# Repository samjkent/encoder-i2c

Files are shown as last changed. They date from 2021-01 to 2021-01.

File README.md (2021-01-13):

# EAW0J 128 Absolute Encoders and LEDs

128 position encoders with LEDs to display state

Encoder input is read using an MCP23017, and LED state is set using an HT16K33

# Large 

128 LEDs in a ring around a single encoder, with a circumference of roughly 6cm

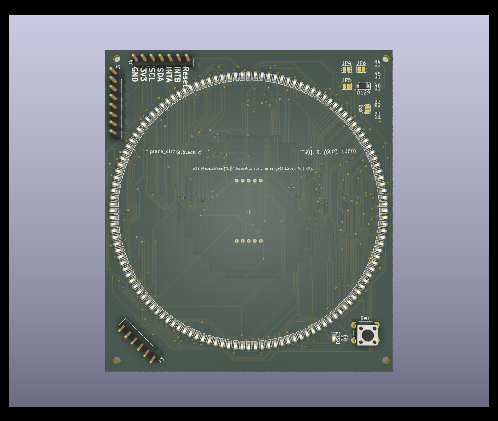
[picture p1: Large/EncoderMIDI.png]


# Small

4 encoders with 32 LEDs per encoder. Requires 2 MCP23017 to provide enough inputs for the encoders.

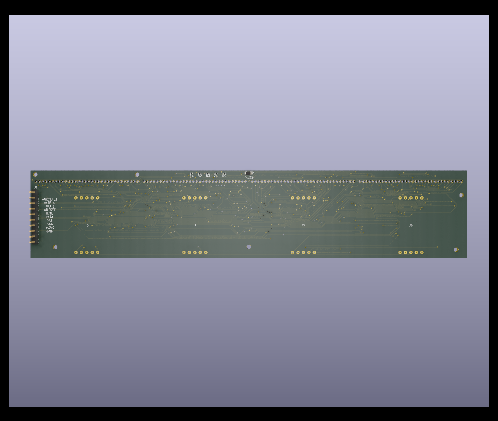
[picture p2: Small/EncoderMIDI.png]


# Example Application

Combined with [samjkent/stm32f4-midi-brain](https://github.com/samjkent/stm32f4-midi-brain) to create a MIDI controller

midi

# Note

The encoder footprint used in these schematics contains a mistake where pins 9 and 10 switched. Software for the current hardware takes this into account.

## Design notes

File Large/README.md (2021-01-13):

# Encoder I2C Large

Kicad layout for a Bourns EAW0J 128 Absolute Encoder with a large ring of LEDs around it

Encoder and LEDs are controlled via I2C (MCP23017, HT16K33)

!(render)[imgurl]

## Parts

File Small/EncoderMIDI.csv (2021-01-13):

Comment | Designator | Footprint | LCSC
LED | D1,D17,D34,D50,D67,D83,D100,D116,D2,D18,D35,D51,D68,D84,D101,D117,D3,D19,D36,D52,D69,D85,D102,D118,D4,D20,D37,D53,D70,D86,D103,D119,D5,D21,D38,D54,D71,D87,D104,D120,D6,D22,D39,D55,D72,D88,D105,D121,D7,D23,D40,D56,D73,D89,D106,D122,D8,D24,D41,D57,D74,D90,D107,D123,D9,D25,D42,D58,D75,D91,D108,D124,D10,D26,D43,D59,D76,D92,D109,D125,D11,D27,D44,D60,D77,D93,D110,D126,D12,D28,D45,D61,D78,D94,D111,D127,D13,D29,D46,D62,D79,D95,D112,D128,D14,D30,D47,D63,D80,D96,D113,D129,D15,D31,D48,D64,D81,D97,D114,D130,D16,D32,D49,D65,D82,D98,D115,D131 | LED_SMD:LED_0603_1608Metric | C2290
D | D132 | Diode_SMD:D_SOD-123F | C162732
Conn_01x10_Female | J1 | Connector_PinHeader_2.54mm:PinHeader_1x10_P2.54mm_Vertical
HT16K33 | J2 | Package_SO:SOIC-28W_7.5x17.9mm_P1.27mm
Conn_01x10_Female | J3,J4,J5,J6 | Rotary_Encoder:EAW0J
SolderJumper_3_Open | JP2,JP5,JP1,JP4,JP6,JP3 | Jumper:SolderJumper-3_P1.3mm_Open_Pad1.0x1.5mm_NumberLabels
SolderJumper_2_Bridged | JP7,JP8 | Jumper:SolderJumper-2_P1.3mm_Bridged2Bar_RoundedPad1.0x1.5mm
SolderJumper_2_Open | JP9,JP10,JP11 | Jumper:SolderJumper-2_P1.3mm_Open_RoundedPad1.0x1.5mm
4.7K | R1,R2 | Resistor_SMD:R_0402_1005Metric | C25940
39K | R3,R4,R5 | Resistor_SMD:R_0402_1005Metric | C159976
MCP23017-E_SO | U1,U2 | Package_SO:SOIC-28W_7.5x17.9mm_P1.27mm

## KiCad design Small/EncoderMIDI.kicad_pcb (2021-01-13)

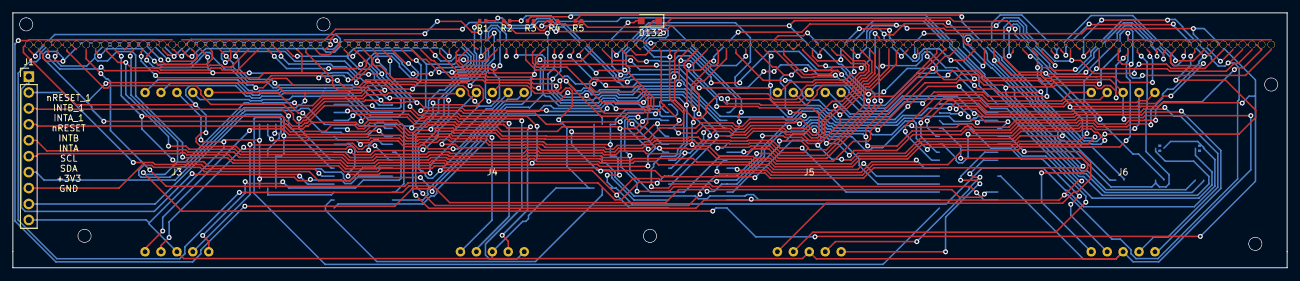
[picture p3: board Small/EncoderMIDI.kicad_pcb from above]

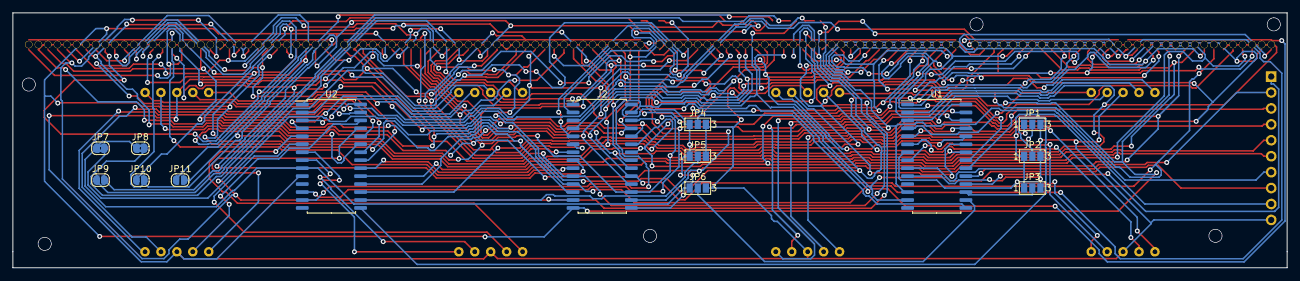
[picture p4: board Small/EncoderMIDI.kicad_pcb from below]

Board: 2 copper layers, 203.2 x 40.6 mm, 153 parts (14 on the bottom side), 58 nets.

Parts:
D1, D2, D3, D4, D5, D6, D7, D8, D9, D10, D11, D12, D13, D14, D15, D16, D17, D18, D19, D20, D21, D22, D23, D24, D25, D26, D27, D28, D29, D30, D31, D32, D34, D35, D36, D37, D38, D39, D40, D41, D42, D43, D44, D45, D46, D47, D48, D49, D50, D51, D52, D53, D54, D55, D56, D57, D58, D59, D60, D61, D62, D63, D64, D65, D67, D68, D69, D70, D71, D72, D73, D74, D75, D76, D77, D78, D79, D80, D81, D82, D83, D84, D85, D86, D87, D88, D89, D90, D91, D92, D93, D94, D95, D96, D97, D98, D100, D101, D102, D103, D104, D105, D106, D107, D108, D109, D110, D111, D112, D113, D114, D115, D116, D117, D118, D119, D120, D121, D122, D123, D124, D125, D126, D127, D128, D129, D130, D131: LED; LED_0603_1608Metric_FPDrillHoleEC
D132: D; D_SOD-123F
J1: Conn_01x10_Female; PinHeader_1x10_P2.54mm_Vertical
J2: HT16K33; SOIC-28W_7.5x17.9mm_P1.27mm
J3, J4, J5, J6: Conn_01x10_Female; EAW0J_FP
JP1, JP2, JP3, JP4, JP5, JP6: SolderJumper_3_Open; SolderJumper-3_P1.3mm_Open_Pad1.0x1.5mm_NumberLabels
JP7, JP8: SolderJumper_2_Bridged; SolderJumper-2_P1.3mm_Bridged2Bar_RoundedPad1.0x1.5mm
JP9, JP10, JP11: SolderJumper_2_Open; SolderJumper-2_P1.3mm_Open_RoundedPad1.0x1.5mm
R1, R2: 4.7K; R_0402_1005Metric
R3, R4, R5: 39K; R_0402_1005Metric
U1, U2: MCP23017-E_SO; SOIC-28W_7.5x17.9mm_P1.27mm

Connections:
+3V3: J1.9, J2.28, JP1.1, JP2.1, JP3.1, JP4.1, JP5.1, JP6.1, JP7.1, JP8.1, U1.9, U2.9
/Sheet5E07A93D/A0: JP2.2, U2.15
/Sheet5E07A93D/A0_1: JP4.2, U1.15
/Sheet5E07A93D/A1: JP5.2, U2.16
/Sheet5E07A93D/A1_1: JP6.2, U1.16
/Sheet5E07A93D/A2: JP1.2, U2.17
/Sheet5E07A93D/A2_1: JP3.2, U1.17
GND: J1.10, J2.1, J3.3, J3.8, J4.3, J4.8, J5.3, J5.8, J6.3, J6.8, JP1.3, JP2.3, JP3.3, JP4.3, JP5.3, JP6.3, U1.10, U2.10
INTA: J1.6, U2.20
INTA_1: J1.3, U1.20
INTB: J1.5, U2.19
INTB_1: J1.2, U1.19
unnamed: D132.2, J2.2
unnamed: J2.25, JP9.2
unnamed: J2.24, JP10.2
unnamed: J2.23, JP11.2
unnamed: D132.1, R3.1, R4.1, R5.1
unnamed: J3.1, U1.1
unnamed: J3.2, U1.2
unnamed: J3.4, U1.3
unnamed: J3.5, U1.4
unnamed: J3.6, U1.5
unnamed: J3.7, U1.6
unnamed: J3.9, U1.7
unnamed: J3.10, U1.8
unnamed: J4.1, U1.21
unnamed: J4.2, U1.22
unnamed: J4.4, U1.23
unnamed: J4.5, U1.24
unnamed: J4.6, U1.25
unnamed: J4.7, U1.26
unnamed: J4.9, U1.27
unnamed: J4.10, U1.28
unnamed: J5.1, U2.1
unnamed: J5.2, U2.2
unnamed: J5.4, U2.3
unnamed: J5.5, U2.4
unnamed: J5.6, U2.5
unnamed: J5.7, U2.6
unnamed: J5.9, U2.7
unnamed: J5.10, U2.8
unnamed: J6.1, U2.21
unnamed: J6.2, U2.22
unnamed: J6.4, U2.23
unnamed: J6.5, U2.24
unnamed: J6.6, U2.25
unnamed: J6.7, U2.26
unnamed: J6.9, U2.27
unnamed: J6.10, U2.28
unnamed: JP7.2, R1.1
unnamed: JP8.2, R2.1
unnamed: JP9.1, R3.2
unnamed: JP10.1, R4.2
unnamed: JP11.1, R5.2
SCL: J1.7, J2.26, R1.2, U1.12, U2.12
SDA: J1.8, J2.27, R2.2, U1.13, U2.13
nRESET: J1.4, U2.18
nRESET_1: J1.1, U1.18

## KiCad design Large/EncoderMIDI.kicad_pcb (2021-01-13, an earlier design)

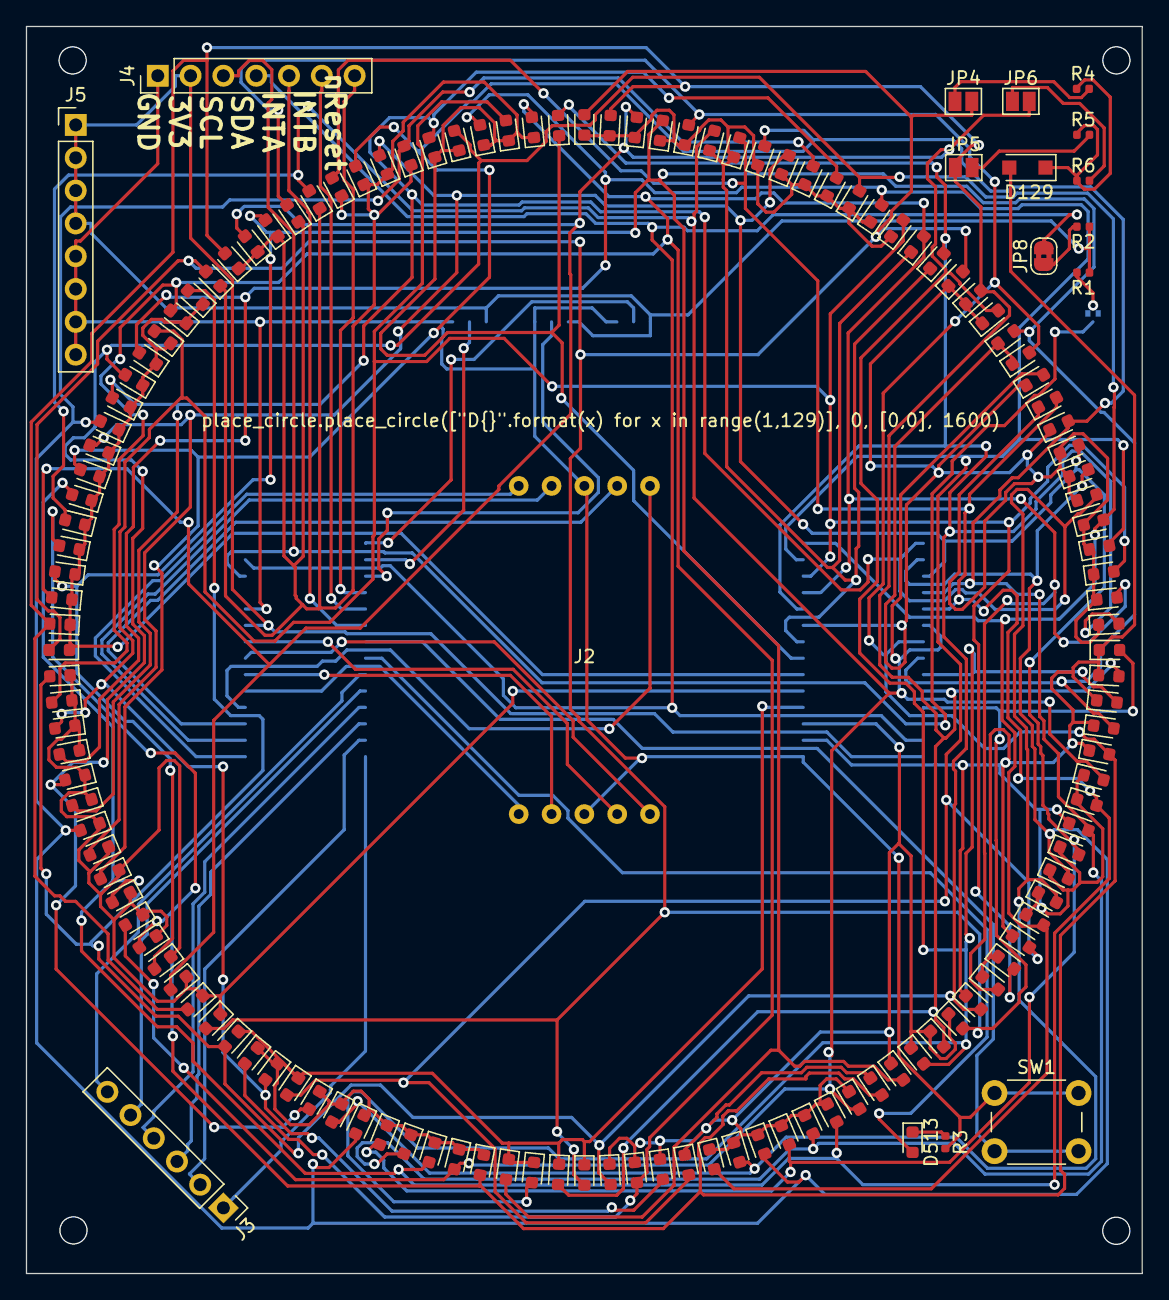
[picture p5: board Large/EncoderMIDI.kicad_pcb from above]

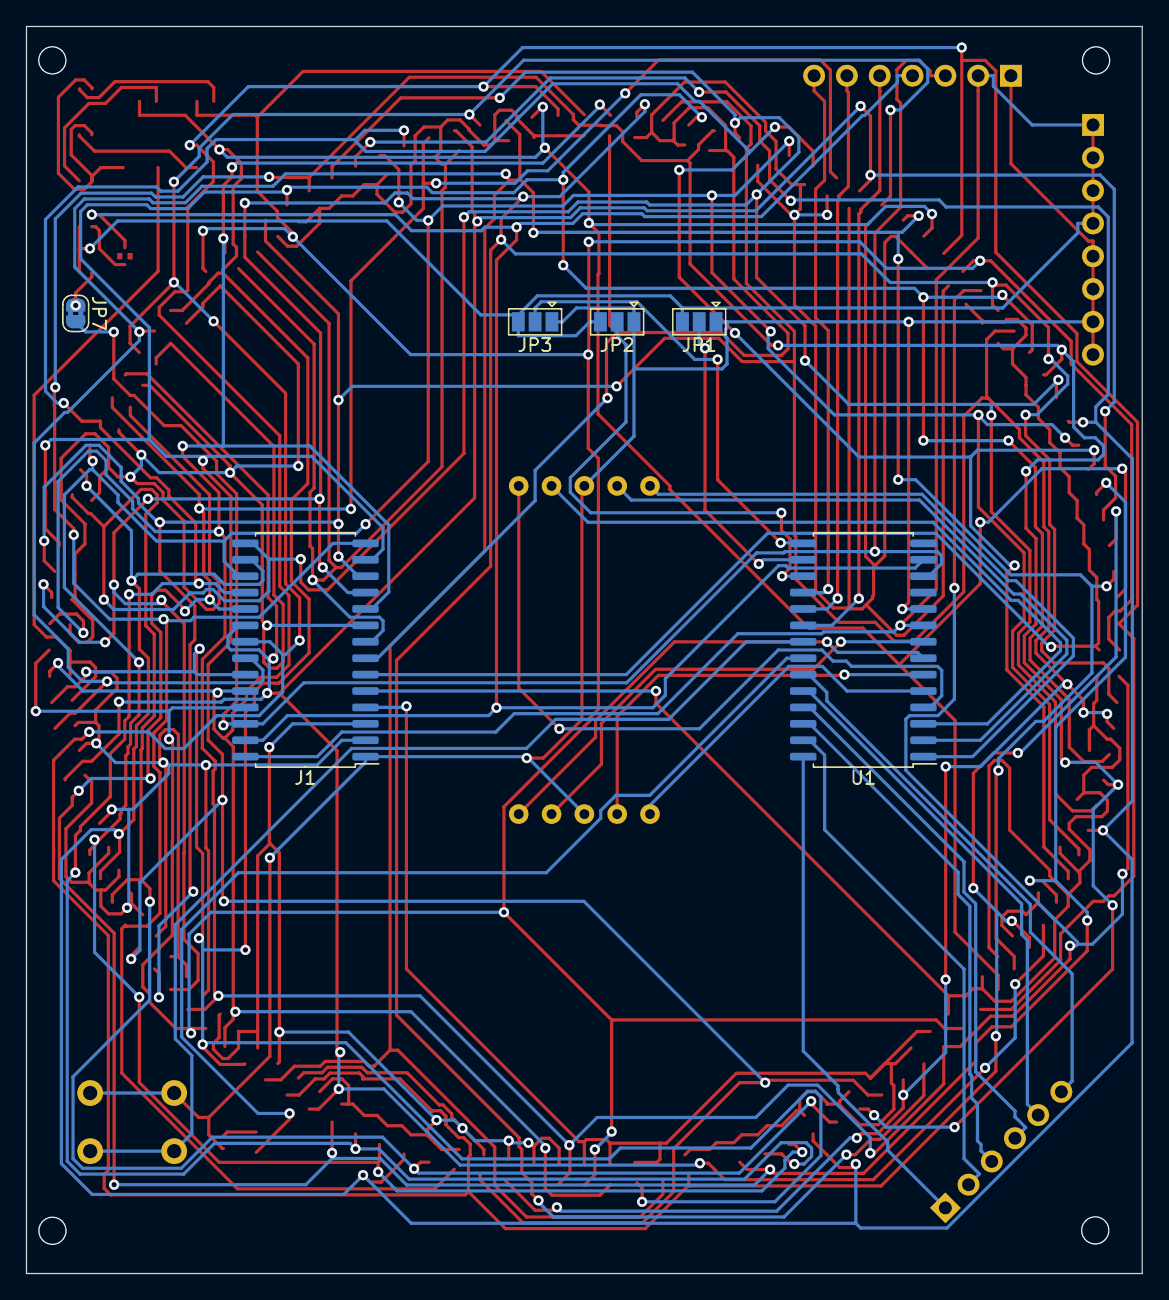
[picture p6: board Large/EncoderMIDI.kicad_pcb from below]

Board: 2 copper layers, 86.4 x 96.5 mm, 151 parts (6 on the bottom side), 57 nets.

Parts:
D1, D2, D3, D4, D5, D6, D7, D8, D9, D10, D11, D12, D13, D14, D15, D16, D17, D18, D19, D20, D21, D22, D23, D24, D25, D26, D27, D28, D29, D30, D31, D32, D33, D34, D35, D36, D37, D38, D39, D40, D41, D42, D43, D44, D45, D46, D47, D48, D49, D50, D51, D52, D53, D54, D55, D56, D57, D58, D59, D60, D61, D62, D63, D64, D65, D66, D67, D68, D69, D70, D71, D72, D73, D74, D75, D76, D77, D78, D79, D80, D81, D82, D83, D84, D85, D86, D87, D88, D89, D90, D91, D92, D93, D94, D95, D96, D97, D98, D99, D100, D101, D102, D103, D104, D105, D106, D107, D108, D109, D110, D111, D112, D113, D114, D115, D116, D117, D118, D119, D120, D121, D122, D123, D124, D125, D126, D127, D128, D513: LED; LED_0603_1608Metric
D129: D; D_SOD-123F
J1: HT16K33; SOIC-28W_7.5x17.9mm_P1.27mm
J2: Conn_01x10_Female; EAW0J
J3: Conn_01x06_Female; PinHeader_1x06_P2.54mm_Vertical
J4: EXT_BUS; PinHeader_1x07_P2.54mm_Vertical
J5: Conn_01x08_Female; PinHeader_1x08_P2.54mm_Vertical
JP1: A1; SolderJumper-3_P1.3mm_Open_Pad1.0x1.5mm
JP2: A2; SolderJumper-3_P1.3mm_Open_Pad1.0x1.5mm
JP3: A0; SolderJumper-3_P1.3mm_Open_Pad1.0x1.5mm
JP4: A2; SolderJumper-2_P1.3mm_Open_Pad1.0x1.5mm
JP5: A1; SolderJumper-2_P1.3mm_Open_Pad1.0x1.5mm
JP6: A0; SolderJumper-2_P1.3mm_Open_Pad1.0x1.5mm
JP7, JP8: SolderJumper_2_Bridged; SolderJumper-2_P1.3mm_Bridged2Bar_RoundedPad1.0x1.5mm
R1, R2: 4.7K; R_0402_1005Metric
R3: R; R_0402_1005Metric
R4, R5, R6: 39K; R_0402_1005Metric
SW1: SW_Push; SW_PUSH_6mm
U1: MCP23017-E_SP; SOIC-28W_7.5x17.9mm_P1.27mm

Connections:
3V3: J1.28, J4.2, J5.1, J5.2, J5.3, J5.4, JP1.3, JP2.3, JP3.3, R1.1, R2.1, U1.9
/large_rotary/A0: JP3.2, U1.15
/large_rotary/A1: JP1.2, U1.16
/large_rotary/A2: JP2.2, U1.17
GND: J1.1, J2.3, J2.8, J4.1, J5.5, J5.6, J5.7, J5.8, JP1.1, JP2.1, JP3.1, R3.2, SW1.1, U1.10
INTA: J4.5, U1.20
INTB: J4.6, U1.19
unnamed: D1.1, D2.1, D3.1, D4.1, D5.1, D6.1, D7.1, D8.1, D9.1, D10.1, D11.1, D12.1, D13.1, D14.1, D15.1, D16.1, D129.2, J1.2
unnamed: D1.2, D17.2, D33.2, D49.2, D65.2, D81.2, D97.2, D113.2, J1.25, JP4.2
unnamed: D10.2, D26.2, D42.2, D58.2, D74.2, D90.2, D106.2, D122.2, J1.16
unnamed: D17.1, D18.1, D19.1, D20.1, D21.1, D22.1, D23.1, D24.1, D25.1, D26.1, D27.1, D28.1, D29.1, D30.1, D31.1, D32.1, J1.3
unnamed: D33.1, D34.1, D35.1, D36.1, D37.1, D38.1, D39.1, D40.1, D41.1, D42.1, D43.1, D44.1, D45.1, D46.1, D47.1, D48.1, J1.4
unnamed: D49.1, D50.1, D51.1, D52.1, D53.1, D54.1, D55.1, D56.1, D57.1, D58.1, D59.1, D60.1, D61.1, D62.1, D63.1, D64.1, J1.5
unnamed: D65.1, D66.1, D67.1, D68.1, D69.1, D70.1, D71.1, D72.1, D73.1, D74.1, D75.1, D76.1, D77.1, D78.1, D79.1, D80.1, J1.6
unnamed: D81.1, D82.1, D83.1, D84.1, D85.1, D86.1, D87.1, D88.1, D89.1, D90.1, D91.1, D92.1, D93.1, D94.1, D95.1, D96.1, J1.7
unnamed: D97.1, D98.1, D99.1, D100.1, D101.1, D102.1, D103.1, D104.1, D105.1, D106.1, D107.1, D108.1, D109.1, D110.1, D111.1, D112.1, J1.8
unnamed: D4.2, D20.2, D36.2, D52.2, D68.2, D84.2, D100.2, D116.2, J1.22
unnamed: D5.2, D21.2, D37.2, D53.2, D69.2, D85.2, D101.2, D117.2, J1.21
unnamed: D6.2, D22.2, D38.2, D54.2, D70.2, D86.2, D102.2, D118.2, J1.20
unnamed: D7.2, D23.2, D39.2, D55.2, D71.2, D87.2, D103.2, D119.2, J1.19
unnamed: D8.2, D24.2, D40.2, D56.2, D72.2, D88.2, D104.2, D120.2, J1.18
unnamed: D9.2, D25.2, D41.2, D57.2, D73.2, D89.2, D105.2, D121.2, J1.17
unnamed: D11.2, D27.2, D43.2, D59.2, D75.2, D91.2, D107.2, D123.2, J1.15
unnamed: D12.2, D28.2, D44.2, D60.2, D76.2, D92.2, D108.2, D124.2, J1.14
unnamed: D13.2, D29.2, D45.2, D61.2, D77.2, D93.2, D109.2, D125.2, J1.13
unnamed: D14.2, D30.2, D46.2, D62.2, D78.2, D94.2, D110.2, D126.2, J1.12
unnamed: D15.2, D31.2, D47.2, D63.2, D79.2, D95.2, D111.2, D127.2, J1.11
unnamed: D16.2, D32.2, D48.2, D64.2, D80.2, D96.2, D112.2, D128.2, J1.10
unnamed: D113.1, D114.1, D115.1, D116.1, D117.1, D118.1, D119.1, D120.1, D121.1, D122.1, D123.1, D124.1, D125.1, D126.1, D127.1, D128.1, J1.9
unnamed: D2.2, D18.2, D34.2, D50.2, D66.2, D82.2, D98.2, D114.2, J1.24, JP5.1
unnamed: D3.2, D19.2, D35.2, D51.2, D67.2, D83.2, D99.2, D115.2, J1.23, JP6.2
unnamed: D129.1, R4.1, R5.1, R6.1
unnamed: D513.1, R3.1
unnamed: D513.2, U1.22
unnamed: J2.1, U1.1
unnamed: J2.2, U1.2
unnamed: J2.4, U1.3
unnamed: J2.5, U1.4
unnamed: J2.6, U1.5
unnamed: J2.7, U1.6
unnamed: J2.9, U1.7
unnamed: J2.10, U1.8
unnamed: J3.1, U1.28
unnamed: J3.2, U1.27
unnamed: J3.3, U1.26
unnamed: J3.4, U1.25
unnamed: J3.5, U1.24
unnamed: J3.6, U1.23
unnamed: JP4.1, R4.2
unnamed: JP5.2, R5.2
unnamed: JP6.1, R6.2
unnamed: JP7.1, R1.2
unnamed: JP8.1, R2.2
unnamed: SW1.2, U1.21
SCL: J1.26, J4.3, JP7.2, U1.12
SDA: J1.27, J4.4, JP8.2, U1.13
nRESET: J4.7, U1.18

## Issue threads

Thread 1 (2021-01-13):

EAW0J Footprint has pins 9 and 10 swapped

samjkent, 2021-01-13:
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

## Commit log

2021-01-13 move to directory:
    [EncoderMIDI.csv, EncoderMIDI.dsn, EncoderMIDI.kicad_pcb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]
2021-01-13 add small
    [EncoderMIDI.csv, EncoderMIDI.dsn, EncoderMIDI.kicad_pcb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]
